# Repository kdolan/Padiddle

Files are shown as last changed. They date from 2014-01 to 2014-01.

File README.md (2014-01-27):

Padiddle
========

Padiddle is the name of a game aimed quickly identifying cars with a burnt out headlight by punching the ceiling. The goal of this project is to create an easy to use hardware/software solution that facilitates the playing of padiddle in a vehicle. The design is composed of an Arduino Uno, two piezoelectric sensors to detect when a user punches the ceiling, and a custom PCB that acts as the user interface.

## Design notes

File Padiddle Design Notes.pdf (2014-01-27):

## Padiddle Design Notes

Design: Kevin J Dolan

Abstract:
Padiddle is the name of a game aimed quickly identifying cars with a burnt out headlight by punching the ceiling. The goal of this project is to create an easy to use hardware/software solution that facilitates the playing of padiddle in a vehicle. The design is composed of an Arduino Uno, two piezoelectric sensors to detect when a user punches the ceiling, and a custom PCB that acts as the user interface.
Parts Lists:
Generic Name | Vender | Vender Code | Quantity | Unit Price | Total
Arduino Uno | Sparkfun | DEV-11021 | 1 | $29.95 | $29.95
10mm Red LED | Sparkfun | COM-00528 | 4 | $0.95 | $3.80
10mm Green LED | Sparkfun | COM-08285 | 2 | $0.95 | $1.90
Red Button | Sparkfun | COM-10442 | 1 | $1.95 | $1.95
Green Button | Sparkfun | COM-10440 | 1 | $1.95 | $1.95
Shift Register | Sparkfun | COM-00733 | 2 | $1.50 | $3.00
Resistors (200 Ω) | DigiKey | 0805 Resistor | 9 | -- | --
Female Headers | Sparkfun | PRT-00115 | 1 | $1.50 | $1.50
7-Segment LED | Sparkfun | COM-08546 | | $0.95
Printed Circuit Board | OSH Park | -- | 3 | $24.45 | $24.45*
TOTAL | | | | | $68.50
*For set of three boards
Design:
A table of the shift registers, their names, and corresponding data is shown below in Table 1.
Table 1 – Shift Register Summary
Shift Register Name | IC | Data
SR-A | 74HC595 | Left 7-Segment Display
SR-B | 74HC595 | Right 7-Segment Display

Each shift register is oriented in the same direction (right facing). Table 2 describes the relationship between the pins of THE shift registers and their corresponding functions.

Table 2 – SR-A & SR-B Wiring Table
Shift Register Label | Shift Register Pin # | LED | LED Pin #
QA | 15 | DP | 5
QB | 1 | G | 10
QC | 2 | F | 9
QD | 3 | E | 1
QE | 4 | D | 2
QF | 5 | C | 4
QG | 6 | B | 6
QH | 7 | A | 7
QH* | 9 | SR-A: Ser_in of SR-B SR-B: Ser_in of SR-C | --

Table 3 provides a detailed description of the pinout for the JP1 connector. The table specifies the function of each pin as well as its corresponding Arduino pin and Arduino variable.
Table 3 – JP1 Connections
JP1 Pin Number | Function | Arduino Pin | Arduino Variable
1 | GND | 14 (GND) | --
2 | Serial | 13 | SERIAL_PIN
3 | CLK | 12 | CLOCK_PIN
4 | LATCH | 11 | LATCH_PIN
5 | Score Button | 10 | SCORE_PIN*
6 | Penalty Button | 9 | PENALTY_PIN*
7 | Left Score LED | 8 | LEFT_SCORE_LED
8 | Left Penalty 1 LED | 7 | LEFT_PENALTY_1_LED
9 | Left Penalty 2 LED | 6 | LEFT_PENALTY_2_LED
10 | Right Score LED | 5 | RIGHT_SCORE_LED
11 | Right Penalty 1 LED | 4 | RIGHT_PENALTY_1_LED
12 | Right Penalty 2 LED | 3 | RIGHT_PENALTY_2_LED
13 | Button LED | 2 | BUTTON_LED
14 | VCC | Power 5V | --
* Pin is an INPUT pin. All other pins are OUTPUT pins.
JP1 is connected to the Arduino with a series of short jumper wires that connect Arduino pin 14 (GND) to Arduino pin 3. A slightly longer jumper wire is then required to connect JP1 pin 14 to VCC (5V).
The left and right piezoelectric sensors are connected to analog inputs A0 and A1 respectively as well as being connected to ground. It is also required to wire a 10M Ohm resistor in parallel with the positive of each sensor and ground. This is accomplished by connecting a resistor between A0 and to ground. An additional resistor is required for A1.

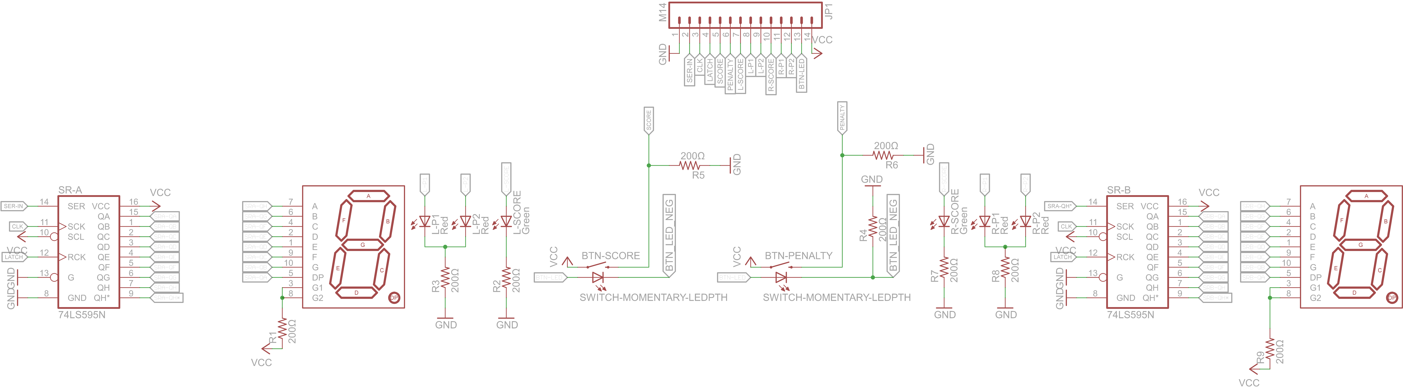
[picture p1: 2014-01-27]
Eagle Files/Schematic Image.png

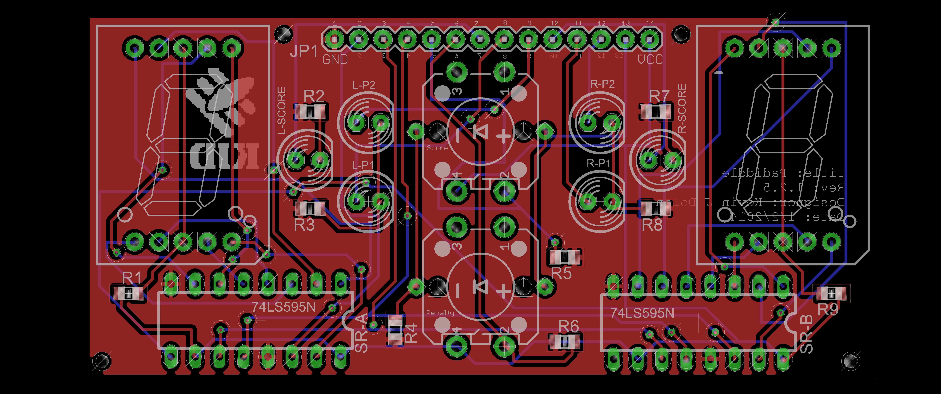
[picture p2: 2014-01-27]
Eagle Files/Board Image.png

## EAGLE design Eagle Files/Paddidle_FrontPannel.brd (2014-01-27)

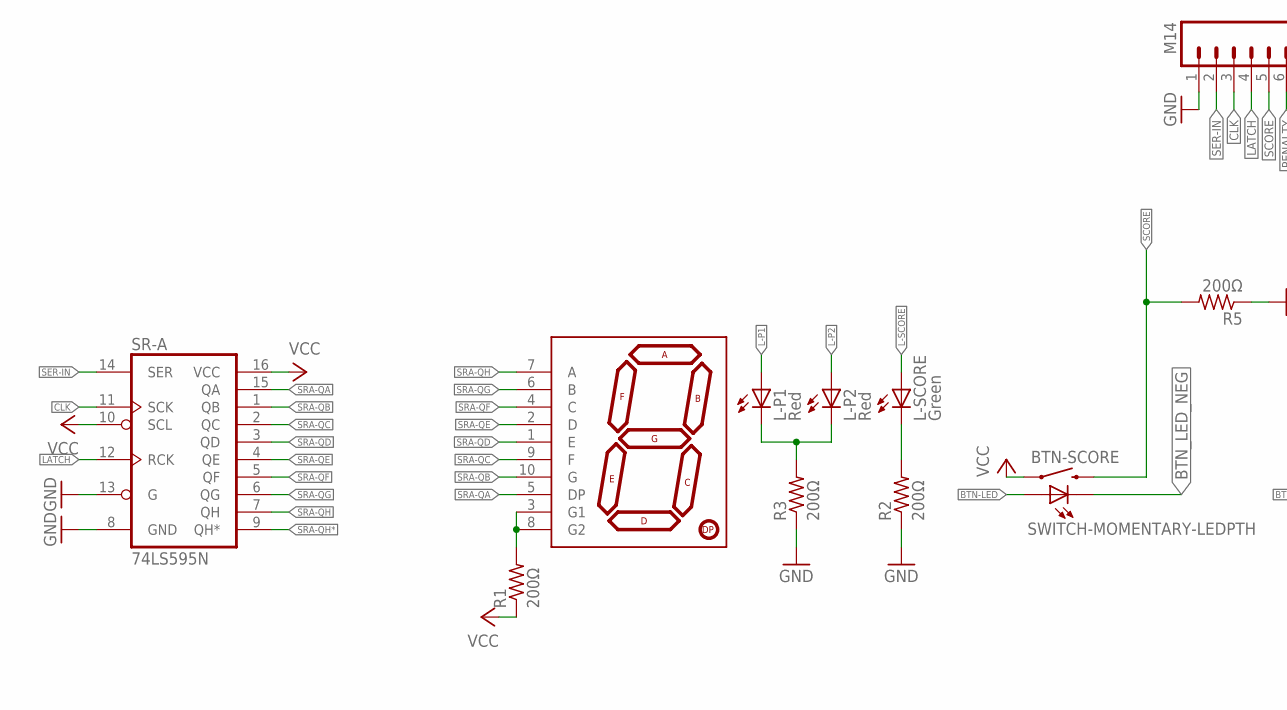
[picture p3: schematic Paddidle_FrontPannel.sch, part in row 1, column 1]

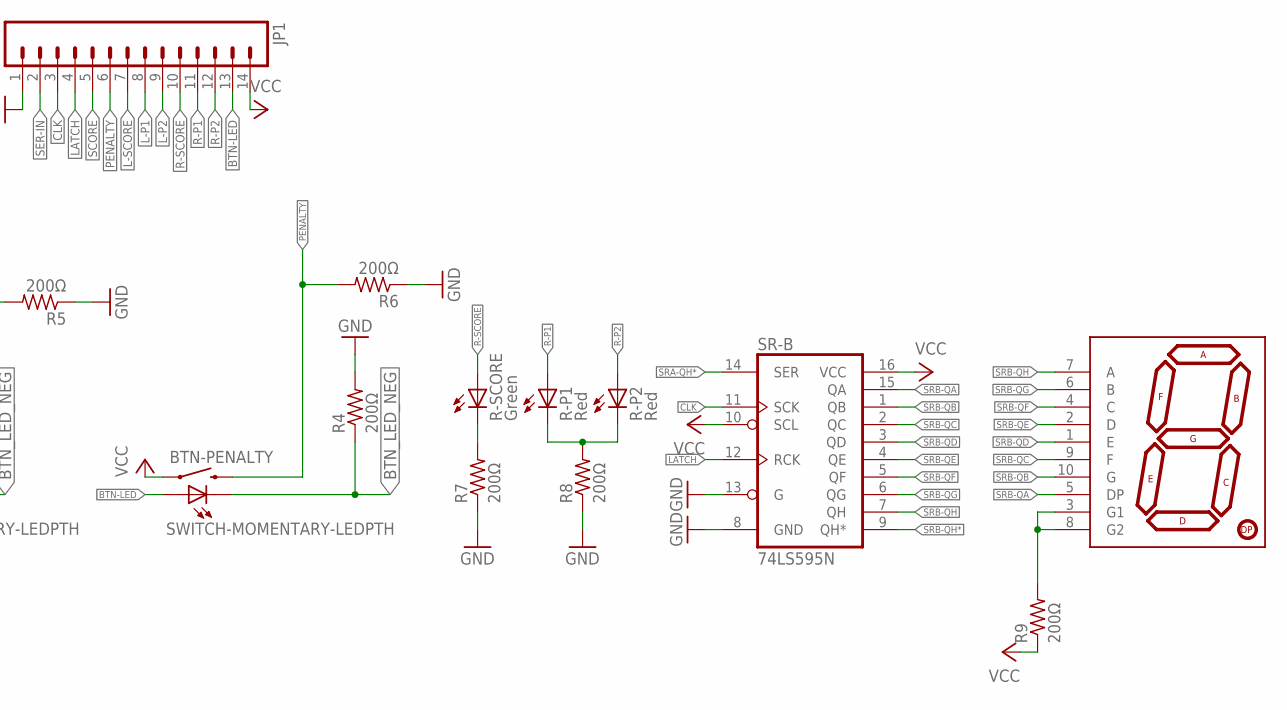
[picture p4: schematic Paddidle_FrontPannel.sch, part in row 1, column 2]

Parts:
7SEG-L, 7SEG-R: 7-SEGMENT-DISPLAY-1"-RED; 7-SEGMENT-1"PTH
BTN-PENALTY: SWITCH-MOMENTARY-LEDPTH; TACTILE-PTH-LED-12MM
BTN-SCORE: SWITCH-MOMENTARY-LEDPTH; TACTILE-PTH-LED-12MM
JP1: M14; 1X14
L-P1, L-P2: Red; LED5MM
L-SCORE: Green; LED5MM
R1, R2, R3, R4, R5, R6, R7, R8, R9: 200Ω; R0805; MPN PFC-W0805LF-03-2000-B
R-P1, R-P2: Red; LED5MM
R-SCORE: Green; LED5MM
SR-A: 74LS595N; DIL16; MPN SN74LS595N
SR-B: 74LS595N; DIL16; MPN SN74LS595N

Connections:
BTN-LED: BTN-PENALTY.A, BTN-SCORE.A, JP1.13
BTN_LED_NEG: BTN-PENALTY.C, BTN-SCORE.C, R4.1
CLK: JP1.3, SR-A.11 (SCK), SR-B.11 (SCK)
GND: JP1.1, R2.1, R3.1, R4.2, R5.1, R6.1, R7.1, R8.1, SR-A.8 (GND), SR-A.13 (G), SR-B.8 (GND), SR-B.13 (G)
L-P1: JP1.8, L-P1.A
L-P2: JP1.9, L-P2.A
L-SCORE: JP1.7, L-SCORE.A
LATCH: JP1.4, SR-A.12 (RCK), SR-B.12 (RCK)
unnamed: L-P1.K (C), L-P2.K (C), R3.2
unnamed: L-SCORE.K (C), R2.2
unnamed: 7SEG-L.3 (G1), 7SEG-L.8 (G2), R1.2
unnamed: R7.2, R-SCORE.K (C)
unnamed: R8.2, R-P1.K (C), R-P2.K (C)
unnamed: 7SEG-R.3 (G1), 7SEG-R.8 (G2), R9.2
PENALTY: BTN-PENALTY.2, JP1.6, R6.2
R-P1: JP1.11, R-P1.A
R-P2: JP1.12, R-P2.A
R-SCORE: JP1.10, R-SCORE.A
SCORE: BTN-SCORE.2, JP1.5, R5.2
SER-IN: JP1.2, SR-A.14 (SER)
SRA-QA: 7SEG-L.5 (DP), SR-A.15 (QA)
SRA-QB: 7SEG-L.10 (G), SR-A.1 (QB)
SRA-QC: 7SEG-L.9 (F), SR-A.2 (QC)
SRA-QD: 7SEG-L.1 (E), SR-A.3 (QD)
SRA-QE: 7SEG-L.2 (D), SR-A.4 (QE)
SRA-QF: 7SEG-L.4 (C), SR-A.5 (QF)
SRA-QG: 7SEG-L.6 (B), SR-A.6 (QG)
SRA-QH: 7SEG-L.7 (A), SR-A.7 (QH)
SRA-QH*: SR-A.9 (QH*), SR-B.14 (SER)
SRB-QA: 7SEG-R.5 (DP), SR-B.15 (QA)
SRB-QB: 7SEG-R.10 (G), SR-B.1 (QB)
SRB-QC: 7SEG-R.9 (F), SR-B.2 (QC)
SRB-QD: 7SEG-R.1 (E), SR-B.3 (QD)
SRB-QE: 7SEG-R.2 (D), SR-B.4 (QE)
SRB-QF: 7SEG-R.4 (C), SR-B.5 (QF)
SRB-QG: 7SEG-R.6 (B), SR-B.6 (QG)
SRB-QH: 7SEG-R.7 (A), SR-B.7 (QH)
SRB-QH*: SR-B.9 (QH*)
VCC: BTN-PENALTY.4 (1), BTN-SCORE.4 (1), JP1.14, R1.1, R9.1, SR-A.10 (SCL), SR-A.16 (VCC), SR-B.10 (SCL), SR-B.16 (VCC)

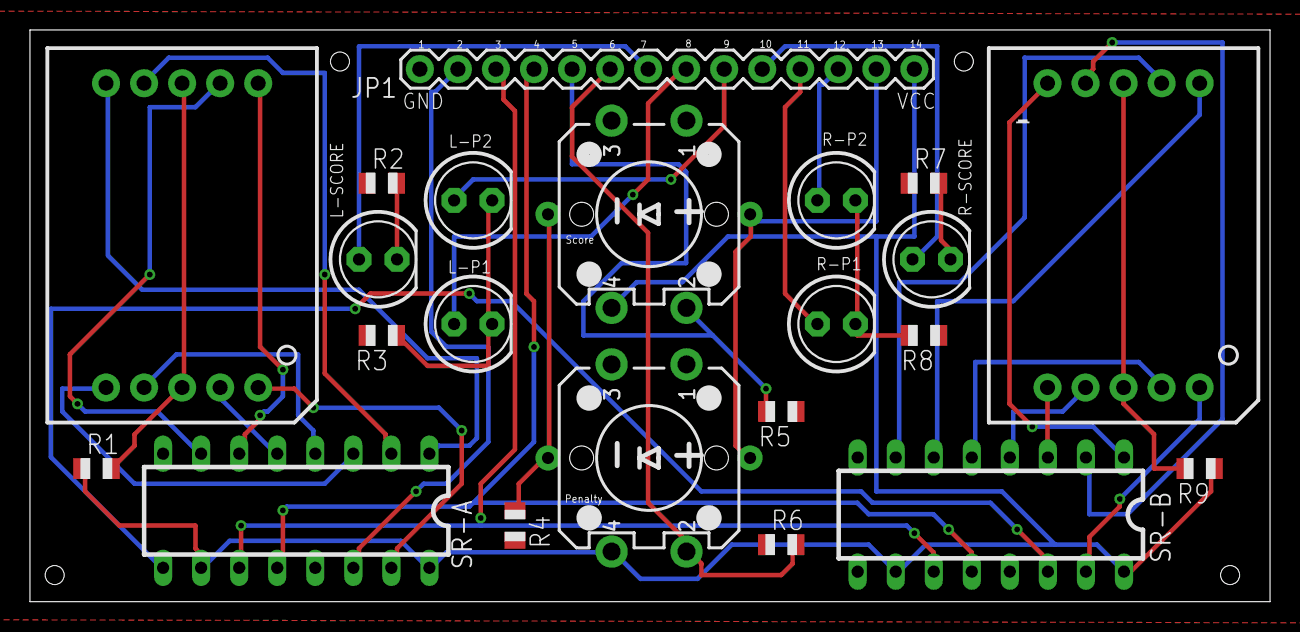
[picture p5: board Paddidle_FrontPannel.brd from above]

Board: 2 copper layers, 82.8 x 38.2 mm, 22 parts (0 on the bottom side), 38 nets.

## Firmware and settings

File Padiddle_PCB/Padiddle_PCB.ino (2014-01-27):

//**************************************************************//
//  Name    : Padiddle                              
//  Author  : Kevin J DOlan
//  Date    : 1/16/2014  
//  Modified: 1/16/2014                              
//  Version : 1.0                                                         
//****************************************************************

//Constants
const boolean LEFT_SIDE = 0;
const boolean RIGHT_SIDE = 1;

const boolean SCORE_BUTTON = 0;
const boolean PENALTY_BUTTON = 1; 


const int THREASHOLD = 45;

//Pinout
const int SERIAL_PIN = 13; //previously AB_dataPin
const int CLOCK_PIN = 12; //previously clockPin
const int LATCH_PIN = 11; //previously AB_latchPin
const int SCORE_PIN = 10;
const int PENALTY_PIN = 9;
const int LEFT_SCORE_LED = 8;
const int LEFT_PENALTY_1_LED = 7;
const int LEFT_PENALTY_2_LED = 6;
const int RIGHT_SCORE_LED = 5;
const int RIGHT_PENALTY_1_LED = 4;
const int RIGHT_PENALTY_2_LED = 3;
const int BUTTON_LED = 2;

//Pin connected to ST_CP of 74HC595
int latchPin = 11;
//Pin connected to SH_CP of 74HC595
int clockPin = 12;
////Pin connected to DS of 74HC595
int dataPin = 13;

const int LEFT_PUNCH_SENSOR = A0; // the piezo is connected to analog pin 0
const int RIGHT_PUNCH_SENSOR = A5; // the piezo is connected to analog pin 1


//Game mode determines the behavior of incScore and incPenalty
//gameMode 0: Friendly game. Inc penalty and score
//gameMode 1: Competitive game. Inc score decreases opponent score if they have no-zero score
  //If both players have zero then score is incremented to 1
  //Penalties do not cancel each other out.
//gameMode 2: Diagnostic. Randomly light all penalty LEDs and time difference from the first
	//sensor activating to the second sensor activating. Print result to screen in milliseconds.
//gameMode 3: Penalty. Same as friendly game except penalties decrease score by 1. Penalty LEDs lit
	//Designates negative score. Max negative score is -2.
const int GM_FRIENDLY = 0; //GM is abbreviation for Game Mode
const int GM_COMPETATIVE = 1;
const int GM_DIAG = 2;
const int GM_PENALTY = 3;

int gameMode = 0;  

const byte numeral[21] = {
    B00000000,  // NULL (Off) --No purpose for zero number. "Off" is zero.
    B01100000,  // 1
    B11011010,  // 2
    B11110010,  // 3
    B01100110,  // 4
    B10110110,  // 5
    B10111110,  // 6
    B11100000,  // 7
    B11111110,  // 8
    B11100110,  // 9
    B11111101,  // 10 (Decimal Set)
    B01100001,  // 11
    B11011011,  // 12
    B11110011,  // 13
    B01100111,  // 14
    B10110111,  // 15
    B10111111,  // 16
    B11100001,  // 17
    B11111111,  // 18
    B11100111,  // 19
    B10011110,  //E
   //ABCDEFGd
};

const byte DISPLAY_LOWERCASE_C = B11100101;//B00011010; //xxxDExGx


//DATA
byte A_data   = B11111111;
byte B_data   = B11111111;
/*
LED PIN MATRIX for 
7(MSB)	: Left Score LED
6		: Left Penalty 1 LED
5		: Left Penalty 2 LED
4		: Right Score LED
3		: Right Penalty 1 LED
2		: Right Penalty 2 LED
1		: Button LED
0(LSB)	: Not Used (Does not correspond to pin -- disconnected)
*/
int LED_pins[8] = {1,1,1,1,1,1,1,1}; //See matrix above


//Penalty Counters
int penaltyRight = 0;
int penaltyLeft = 0;
//Score counters
int scoreRight = 0;
int scoreLeft = 0;


//CLASS DEC
class Game {
  public:
    virtual void incScore(boolean sideOfCar);
    inline virtual void incPenalty(boolean sideOfCar)
	{
		if(sideOfCar == RIGHT_SIDE)
		{
			penaltyRight++;
		}
		else
		{
			penaltyLeft++;
		}
	};
    inline virtual void decScore(boolean sideOfCar)
    {
      if(sideOfCar == RIGHT_SIDE)
      {
            scoreRight--;
            if(scoreRight < 0)
            {
               scoreRight = 19; 
            }
       }
       else //LEFT_SIDE 
       {
            scoreLeft--;
            if(scoreLeft < 0)
            {
               scoreLeft = 19; 
            }
       } 
    };
    inline virtual int getScoreLeft()
    {
      return scoreLeft;
    };
    inline virtual int getScoreRight()
    {
      return scoreRight;
    };
    inline virtual int getPenaltyLeft()
    {
      return penaltyLeft;
    };
    inline virtual int getPenaltyRight()
    {
      return penaltyRight;
    };
  protected:
    int scoreLeft;
    int scoreRight;
    int penaltyLeft;
    int penaltyRight;
};

//Friendly Game
class FriendlyGame : public Game {
  public:
    inline FriendlyGame(){
        scoreLeft = 0;
        scoreRight = 0;
        penaltyLeft = 0;
        penaltyRight = 0;
    }
    virtual void incScore(boolean sideDetected);
};

void FriendlyGame::incScore(boolean sideDetected)
{
  if(sideDetected == RIGHT_SIDE)
  {
      scoreRight++;
  }
  else
  {
      scoreLeft++;
  }
}

//End Friendly Game
//CompetitiveGame
class CompetitiveGame : public Game {
  public:
    inline CompetitiveGame(){
        scoreLeft = 0;
        scoreRight = 0;
        penaltyLeft = 0;
        penaltyRight = 0;
    }
    virtual void incScore(boolean sideDetected);
};

void CompetitiveGame::incScore(boolean sideDetected)
{
  if(sideDetected == RIGHT_SIDE)
  {
	 if(scoreRight >= 0 && scoreLeft == 0)
	  {
		  //inc score right
		  scoreRight++;
		  Serial.println("Right ahead or both zero. INC RIGHT");
	  }
	  else
	  {
		 //Score left must be higher. Dec left score
		 Serial.println( "Left ahead. DEC LEFT");
		 scoreLeft--; 
	  }
  }
  else
  {
	  if(scoreRight == 0 && scoreLeft >= 0)
	  {
		  //inc score left
		  scoreLeft++;
		  Serial.println("Left ahead or both zero. INC LEFT");
	  }
	  else
	  {
		 //Score right must be higher. Dec right score
		 scoreRight--; 
		 Serial.println( "Right ahead. DEC RIGHT");
	  }
  }
}
//End CompetitiveGame

//PenaltyGame
class PenaltyGame : public Game {
  public:
    inline PenaltyGame(){
        scoreLeft = 0;
        scoreRight = 0;
        penaltyLeft = 0;
        penaltyRight = 0;
    }
    virtual void incScore(boolean sideDetected);
    virtual void incPenalty(boolean sideDetected);
};

void PenaltyGame::incScore(boolean sideDetected)
{
	if(sideDetected == RIGHT_SIDE)
	{
		if(penaltyRight == 0)
		{
			scoreRight++;
		}
		else
		{
			penaltyRight--;
		}
	}
	else
	{
		if(penaltyLeft == 0)
		{
			scoreLeft++;
		}
		else
		{
			penaltyLeft--;
		}
	}
}

void PenaltyGame::incPenalty(boolean sideDetected)
{
	if(sideDetected == RIGHT_SIDE)
	{
		if(scoreRight == 0)
		{
			penaltyRight++;
                        if(penaltyRight > 2)
                        {
                          penaltyRight = 2;
                        }
		}
		else
		{
			scoreRight--;
		}
	}
	else
	{
		if(scoreLeft == 0)
		{
			penaltyLeft++;
                        if(penaltyLeft > 2)
                        {
                          penaltyLeft = 2;
                        }
		}
		else
		{
			scoreLeft--;
		}
	}
}

//Game Setup
Game* game;

FriendlyGame friendly;
CompetitiveGame competitive;
PenaltyGame penalty;



void setup() {
  Serial.begin(9600);      // open the serial port at 9600 bps:  
  Serial.println("Begin setup");
  
  //set pins to output so you can control the shift register
  //PIN SETUP
  pinMode(SERIAL_PIN, OUTPUT); //13
  pinMode(CLOCK_PIN, OUTPUT); //12
  pinMode(LATCH_PIN, OUTPUT); //11
  pinMode(SCORE_PIN, INPUT); //10
  pinMode(PENALTY_PIN, INPUT); //9
  pinMode(LEFT_SCORE_LED, OUTPUT); //8
  pinMode(LEFT_PENALTY_1_LED, OUTPUT); //7
  pinMode(LEFT_PENALTY_2_LED, OUTPUT); //6
  pinMode(RIGHT_SCORE_LED, OUTPUT); //5 
  pinMode(RIGHT_PENALTY_1_LED, OUTPUT); //4
  pinMode(RIGHT_PENALTY_2_LED, OUTPUT); //3
  pinMode(BUTTON_LED, OUTPUT); //2
  
  pinMode(latchPin, OUTPUT);
  pinMode(clockPin, OUTPUT);
  pinMode(dataPin, OUTPUT);
  
  //Test display (All LEDs on for 250ms)
  Serial.println("Test display");
  //Test 7-Seg Displays
  //Test LEDs
  setLEDs();
  
  //All Status LEDs are still lit. Test 7-Seg displays with number cycle
  Serial.println("Number Cycle");
  cycleNumbers(100);
  //Clear status LEDs. Light buttons
  setLEDs(0,0,0,0,0,0,1);
  Serial.println("End Setup");
  
  //GAME MODE SELECT
  Serial.println("Begin game select mode");
  B_data = DISPLAY_LOWERCASE_C;
  shiftOutScore();
  //Countdown 3...2...1... on Right display
  
  countdown(3); //Countdown from 3
  
  int configPin_0_state = digitalRead(PENALTY_PIN); //The bottom button (penalty) in config mode is pin0
  int configPin_1_state = digitalRead(SCORE_PIN); //The top button (score) in config mode is pin1
  
  //Determine GameMode
  if(configPin_1_state == LOW  && configPin_0_state == LOW) //00 (0)
  {
    gameMode = GM_PENALTY;
    game = &penalty;
  }
  else if(configPin_1_state == LOW  && configPin_0_state == HIGH ) //01 (1)
  {
    gameMode = GM_COMPETATIVE;
    game = &competitive;
  }
  else if(configPin_1_state == HIGH  && configPin_0_state == LOW ) //10 (2)
  {
    gameMode = GM_DIAG;
  }
  else //11 (3)
  {
     gameMode = GM_FRIENDLY;
     game = &friendly;     
  }
  Serial.print("Game Mode selected. Current game mode: ");   Serial.println(gameMode, DEC);
  
  //Display selected gamemode on B display for 500 ms.
  setScoreRight(gameMode);
  setScoreLeft(0); //Clear left dispaly
  setLEDs(0,0,0,0,0,0,0); //Unset button LED
  delay(2000);
  setScoreRight(0);
  setScoreLeft(0);
  Serial.println("End setup");
  //Begin game!

   
}

void loop() {
    Serial.println("Enter game loop");
    boolean sideDetected;
    if(gameMode == GM_DIAG)
    {
        Serial.print("Start Diag Mode");
        //Diagnostic loop
        while(true)
        {
           unsigned long startTime = millis(); //Record time when light is lit
           unsigned long firstHit;
           unsigned long secondHit;
           boolean firstSide;
           countdown(3); //Countdown from 3
           setScoreRight(0);
           shiftOutScore();
           int timeDelay = random(1000, 10000); //delay between 1 and 10 sec
           delay(timeDelay);
           
           setLEDs(0,1,1,0,1,1,0); //Turn on all penalty lights
           
           //Wait for first punch
            
           while(true)
           {
              int leftSensorValue = analogRead(LEFT_PUNCH_SENSOR);
              int rightSensorValue = analogRead(RIGHT_PUNCH_SENSOR);
              if(leftSensorValue>=THREASHOLD)
              {
                //LEFT DETECTED
                setScoreLED(LEFT_SIDE); //Set score left
                firstHit = millis();
                firstSide = LEFT_SIDE;
                break;
              }
              else if(rightSensorValue>=THREASHOLD)
              {
                //RIGHT DETECTED
                setScoreLED(RIGHT_SIDE); //Set score left
                firstHit = millis();
                firstSide = RIGHT_SIDE;
                break;
              }
           }
           Serial.print("Reaction Time: ");
           Serial.print(firstHit - startTime - timeDelay);
           Serial.println("ms"); 
         //Wait for second punch
           while(true)
           {
              int leftSensorValue = analogRead(LEFT_PUNCH_SENSOR);
              int rightSensorValue = analogRead(RIGHT_PUNCH_SENSOR);
              if(leftSensorValue>=THREASHOLD && firstSide == RIGHT_SIDE)
              {
                //LEFT DETECTED
                secondHit = millis();
                break;
              }
              else if(rightSensorValue>=THREASHOLD && firstSide == LEFT_SIDE)
              {
                //Right DETECTED
                secondHit = millis();
                break;
              }
           }
           Serial.print("Delay Between Hits: ");
           Serial.print(secondHit - firstHit);
           Serial.println("ms");
           Serial.println("/-----------------------\\");
           setLEDs(0,0,0,0,0,0,0); //Clear all lights
        }
    }
    while(true) //Wait until a sensor is triggered.
    {
      pushData();
      int leftSensorValue = analogRead(LEFT_PUNCH_SENSOR);
      int rightSensorValue = analogRead(RIGHT_PUNCH_SENSOR);
      if(leftSensorValue>=THREASHOLD)
      {
        //LEFT DETECTED
        sideDetected = LEFT_SIDE;
        setScoreLED(LEFT_SIDE); //Set score left
        Serial.print("LEFT - ");
        Serial.print(leftSensorValue);
        Serial.println("");
        break;
      }
      else if(rightSensorValue>=THREASHOLD)
      {
        //RIGHT DETECTED
        sideDetected = RIGHT_SIDE;
        setScoreLED(RIGHT_SIDE); //Set score right
        Serial.print("RIGHT - ");
        Serial.print(rightSensorValue);
        Serial.println("");
        break;    
      }
      else
      {
         //Not detected. Check for score decrement
         int scoreState_LeftDec= digitalRead(SCORE_PIN);
         int penaltyState_RightDec = digitalRead(PENALTY_PIN);
         if(scoreState_LeftDec == HIGH)
         {
              //Decrement socre left
              game->decScore(LEFT_SIDE);
              waitForbuttonRelease(SCORE_BUTTON);
         }
         else if (penaltyState_RightDec == HIGH)
         {
              //Decrement socre right
              game->decScore(RIGHT_SIDE);
              waitForbuttonRelease(PENALTY_BUTTON);

         }
         continue; //Restart loop
      }
    }  //End While loop to check for sensor detection. Wait for button input
    boolean score = isScore(); //Wait for score or penalty button to be pushed
    unsetScoreLEDs();
    if(score)
    {
        //Increment counter
        game->incScore(sideDetected);
        pushData();
        waitForbuttonRelease(SCORE_BUTTON);
    }
    else
    {
       //Penalty
       game->incPenalty(sideDetected);
       pushData();
       waitForbuttonRelease(PENALTY_BUTTON);
    }
}//End loop


boolean isScore(){
 int score = 0; //0 is unset
 while(score==0)
  {
    int scoreState = digitalRead(SCORE_PIN);
    int penaltyState = digitalRead(PENALTY_PIN);
    if(scoreState == HIGH)
    {
         return true;
    }
    else if (penaltyState == HIGH)
    {
         return false;
    }
  }
}

void waitForbuttonRelease(boolean button)
{
   if(button == PENALTY_BUTTON)
   {
       //Wait until button is released
       while(digitalRead(PENALTY_PIN) == HIGH)
       {
          //wait for button to go low
       }
       Serial.println("Penalty button released");
       return;
   }
   else
   {
       //Wait until button is released
       while(digitalRead(SCORE_PIN) == HIGH)
       {
          //wait for button to go low
       }
       Serial.println("Score button released");
       return; 
   }
 }


void setScoreLeft(int num)
{
  //B_data
  B_data = B11111111 ^ numeral[num]; //Bitwise XOR to invert each value for active low enable
  shiftOutScore();
}

void setScoreRight(int num)
{
  //A_data
  A_data = B11111111 ^ numeral[num]; //Bitwise XOR to invert each value for active low enable
  shiftOutScore();
}

/*
LED PIN MATRIX for 
7(MSB)	: Left Score LED
6		: Left Penalty 1 LED
5		: Left Penalty 2 LED
4		: Right Score LED
3		: Right Penalty 1 LED
2		: Right Penalty 2 LED
1		: Button LED
0(LSB)	: Not Used (Does not correspond to pin -- disconnected)
*/
void setLEDs(int leftScore, int leftPenalty1, int leftPenalty2, int rightScore, int rightPenalty1, 
	int rightPenalty2, int buttonLED) //previously shiftOutC()
{
	LED_pins[7] = leftScore;
	LED_pins[6] = leftPenalty1;
	LED_pins[5] = leftPenalty2;
	LED_pins[4] = rightScore;
	LED_pins[3] = rightPenalty1;
 	LED_pins[2] = rightPenalty2;
	LED_pins[1] = buttonLED;

	setLEDs();
}

void setLEDs() //previously shiftOutC()
{
	digitalWrite(LEFT_SCORE_LED, LED_pins[7]);
	digitalWrite(LEFT_PENALTY_1_LED, LED_pins[6]);
	digitalWrite(LEFT_PENALTY_2_LED, LED_pins[5]);
	digitalWrite(RIGHT_SCORE_LED, LED_pins[4]);
	digitalWrite(RIGHT_PENALTY_1_LED, LED_pins[3]);
	digitalWrite(RIGHT_PENALTY_2_LED, LED_pins[2]);
	digitalWrite(BUTTON_LED, LED_pins[1]);
}

void setScoreLED(boolean side)
{
	if(side == LEFT_SIDE)
	{
		LED_pins[7] = 1;
	}
	else //RIGHT_SIDE
	{
		LED_pins[4] = 1;
	}
        LED_pins[1] = 1;
	setLEDs();
}

void unsetScoreLEDs(){
	LED_pins[7] = 0;
	LED_pins[4] = 0;
	setLEDs();
}


void shiftOutScore() //previously shiftOutAB()
{
  digitalWrite(LATCH_PIN, LOW);
  // shift out the bits for highbyte (A)
  shiftOut(SERIAL_PIN, CLOCK_PIN, MSBFIRST, A_data); 
  // shift out lowbyte (B)
  shiftOut(SERIAL_PIN, CLOCK_PIN, MSBFIRST, B_data);
  digitalWrite(LATCH_PIN, HIGH);
}

void cycleNumbers(int cycleInterval)
{
  for(int i = 0; i <21; i++)
  {
    setScoreRight(i);
    setScoreLeft(i);
    if(i!=20)
    {
      delay(cycleInterval);
    }
  }
    setScoreRight(0);
    setScoreLeft(0);
}

void countdown(int startingNumber)
{
	int currentNum = startingNumber;
	while(currentNum > 0)
	{
		setScoreRight(currentNum);
		currentNum--;
		delay(1000); //Wait for 1 sec 
	}
}

void pushData()
{
  //Set score
   setScoreLeft(game->getScoreLeft());
   setScoreRight(game->getScoreRight());
  //Determine penalty LEDs to light
  int leftP1 = 0;
  int leftP2 = 0;
  int rightP1 = 0;
  int rightP2 = 0;
  //Left
  int penaltyLeft = game->getPenaltyLeft();
  if(penaltyLeft == 1)
  {
    leftP1 = 1;
  }
  else if(penaltyLeft == 2)
  {
    leftP1 = 1;
    leftP2 = 1;
  }
  //Right 
  int penaltyRight = game->getPenaltyRight();
  if(penaltyRight == 1)
  {
    rightP1 = 1;
  }
  else if(penaltyRight == 2)
  {
    rightP1 = 1;
    rightP2 = 1;
  }
  //Set LEDs
   setLEDs(0,leftP1,leftP2,0,rightP1,rightP2,0);
}


//End PenaltyGame

/*FriendlyGame friendly;
void setup() {
  // put your setup code here, to run once:
  Game* game = &friendly;
  game->incScore(LEFT_SIDE);
}

void loop() {
  // put your main code here, to run repeatedly: 
  
}*/

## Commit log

2013-11-03 Code cleanup & Bug Fixes
    -Primary loop is simpler and less verbose.
    -Fixed bug where sensor would trigger many successive penalty or score
    increases while button was pressed. Program now waits until button is
    released to begin checking for input again.
2013-11-04 Adds configuration and competitive game mode
    -Adds configuration with binary switches on pins 4 and 5. Ability to
    change game mode to competitive . Competitive mode allows only one
    person to have a score (ie score cancelation).
    -Misc code improvements
    -Removes zero as a number for numerals constant. Zero is replaced by
    null value (led display off).
2013-11-10 Decrement Score Feature
    Ability to decrement the score of left and right using the penalty and
    score buttons when the score LEDs are not set. Pressing the score button
    decrements left while the penalty button decrements right.
2014-01-27 Redesign and Printed Circuit Board
    This commit includes a complete redesign of the code base as well as
    includes an eagle schematic for a PCB.
    [Paddidle_FrontPannel.brd, Paddidle_FrontPannel.sch]

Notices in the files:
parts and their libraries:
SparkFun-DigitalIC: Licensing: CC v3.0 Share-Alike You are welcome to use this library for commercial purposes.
